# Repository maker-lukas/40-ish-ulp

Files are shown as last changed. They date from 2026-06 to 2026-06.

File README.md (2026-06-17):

# 40%ish ulp

> A split wireless 36 key keyboard powered by the Seeed XIAO Nrf52840 with cherry ULP switches.

<div>
  <a target="_blank" href="https://kicanvas.org/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">
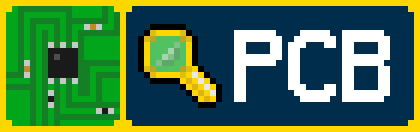
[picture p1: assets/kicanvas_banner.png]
View on KiCanvas
    
  </a>
</div>

<div>
  <a target="_blank" href="https://autode.sk/3Qic5Ux">
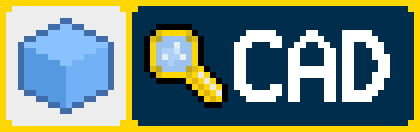
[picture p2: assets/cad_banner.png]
View CAD
    
  </a>
</div>

<div align="center">
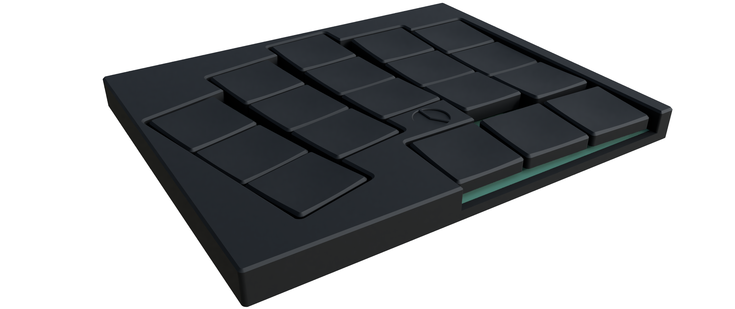
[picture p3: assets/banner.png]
  
</div>

---

**40%ish** ulp is a split, ultra low profile keyboard with a 36 key layout, which is great when you are traveling or like a clean and slim build on your desk. It's only 8.25mm thick, with a huge battery so you won't have to charge it every day. It even has a status LED to tell you when the battery is low. Being wireless, it can connect to any device. Using ZMK firmware, you can customize your layout on the fly inside your browser, and its really power efficient!

---

## Features

- 36 key split layout
- Wireless BLE with ZMK
- Cherry ULP switches
- Reversible PCB design

---

## BOM
 
| Part | Qty | Specification | Price | Link |
|---|-----|---|---|---|
| MCU | 2 | Seeed XIAO nRF52840 | $26.18 | [mauser.pt](https://mauser.pt/095-1482/seeed-102010448-microcontrolador-seeed-studio-xiao-nrf52840-c-bluetooth-5-0-ble-nfc-e-carregamento-de-bateria) |
| Switches (pack of 10) | 4 | Cherry ULP | $41.63 | [keeb.supply](https://keeb.supply/products/cherry-mx-ulp?variant=a840d9fa-f4e0-4218-be04-4d0f5e8f7554) |
| PCBs | 5 | Reversible, MOQ 5 | $11.06 | [jlcpcb.com](https://jlcpcb.com) |
| Batteries | 2 | 307095, 5000mAh battery | $16.23 | [aliexpress.com](https://pt.aliexpress.com/item/1005009973979747.html) |
| Diodes | 36 | SOD-123 | $1.57 | [aliexpress.com](https://pt.aliexpress.com/item/1005012163356976.html) |
| Power Switch | 2 | MK-12C02 | $0.87 | [aliexpress.com](https://pt.aliexpress.com/item/1005011530988236.html) |
| Reset Switch | 2 | EVQ-PUL02K | $1.87 | [aliexpress.com](https://pt.aliexpress.com/item/1005010726427079.html) |
| LEDs | 2 | WS2812B | $1.14 | [aliexpress.com](https://pt.aliexpress.com/item/1005008739048100.html) |
| Case | 2 | | $6.42 | [jlc3dp.com](https://jlc3dp.com) |
| Keycaps | 36 | Resin Printed | $37.46 | [jlc3dp.com](https://jlc3dp.com) |
| Magnets | 8 | 5x2mm round magnets | $2.88 | [aliexpress.com](https://pt.aliexpress.com/item/1005009605352565.html) |
| **Total** | | | **$147.31** | |

---

## Soldering notes

Because the PCB is reversible, some of the pins need to be reversed by bridging solder jumpers. Solder all 5 points shown in the images below for each side.

| Left | Right |
|:---:|:---:|
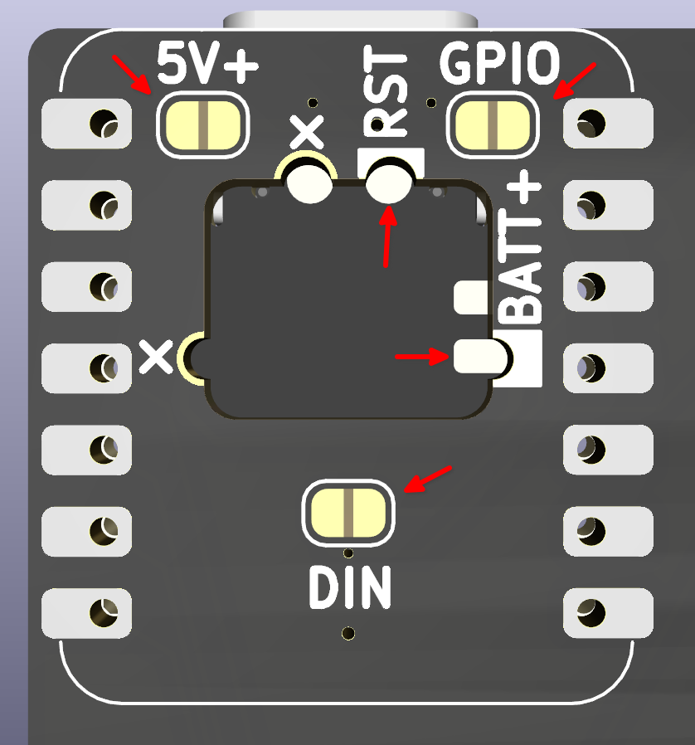
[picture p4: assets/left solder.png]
solder_left
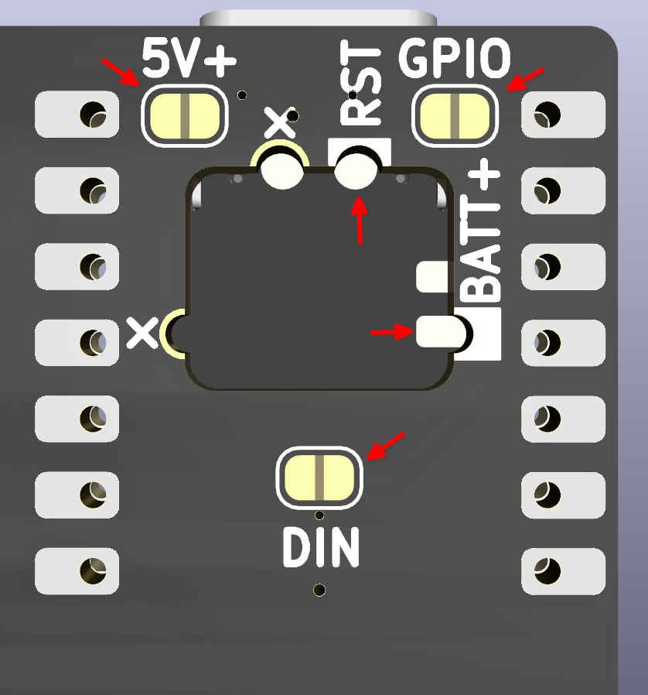
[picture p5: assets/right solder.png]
solder_right
|  |  |

---

## Pictures

| |
|:---:|
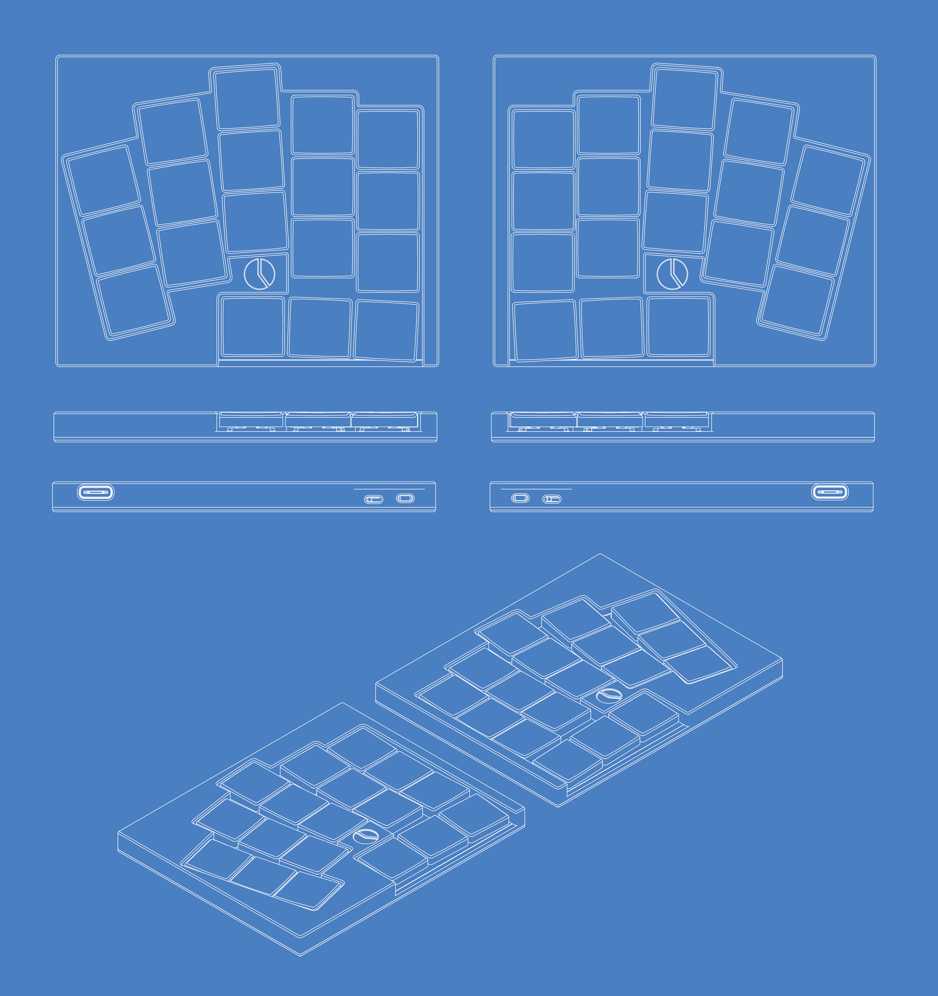
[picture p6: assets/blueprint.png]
blueprint
| **Blueprint**<br><br> |
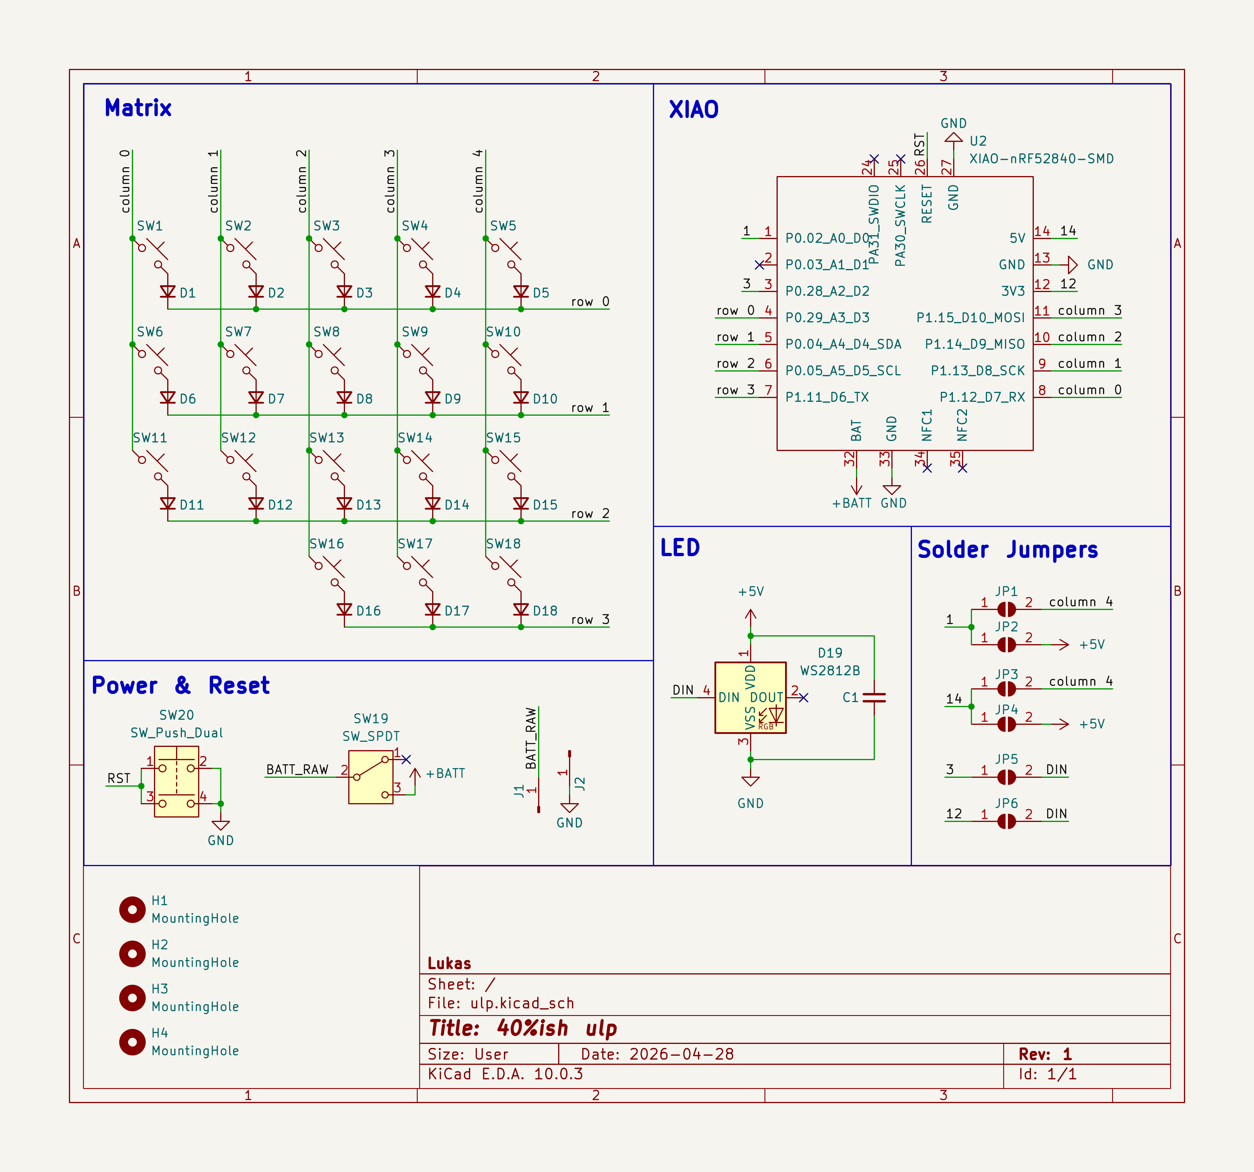
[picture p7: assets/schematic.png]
schematic
| **Schematic**<br><br> |
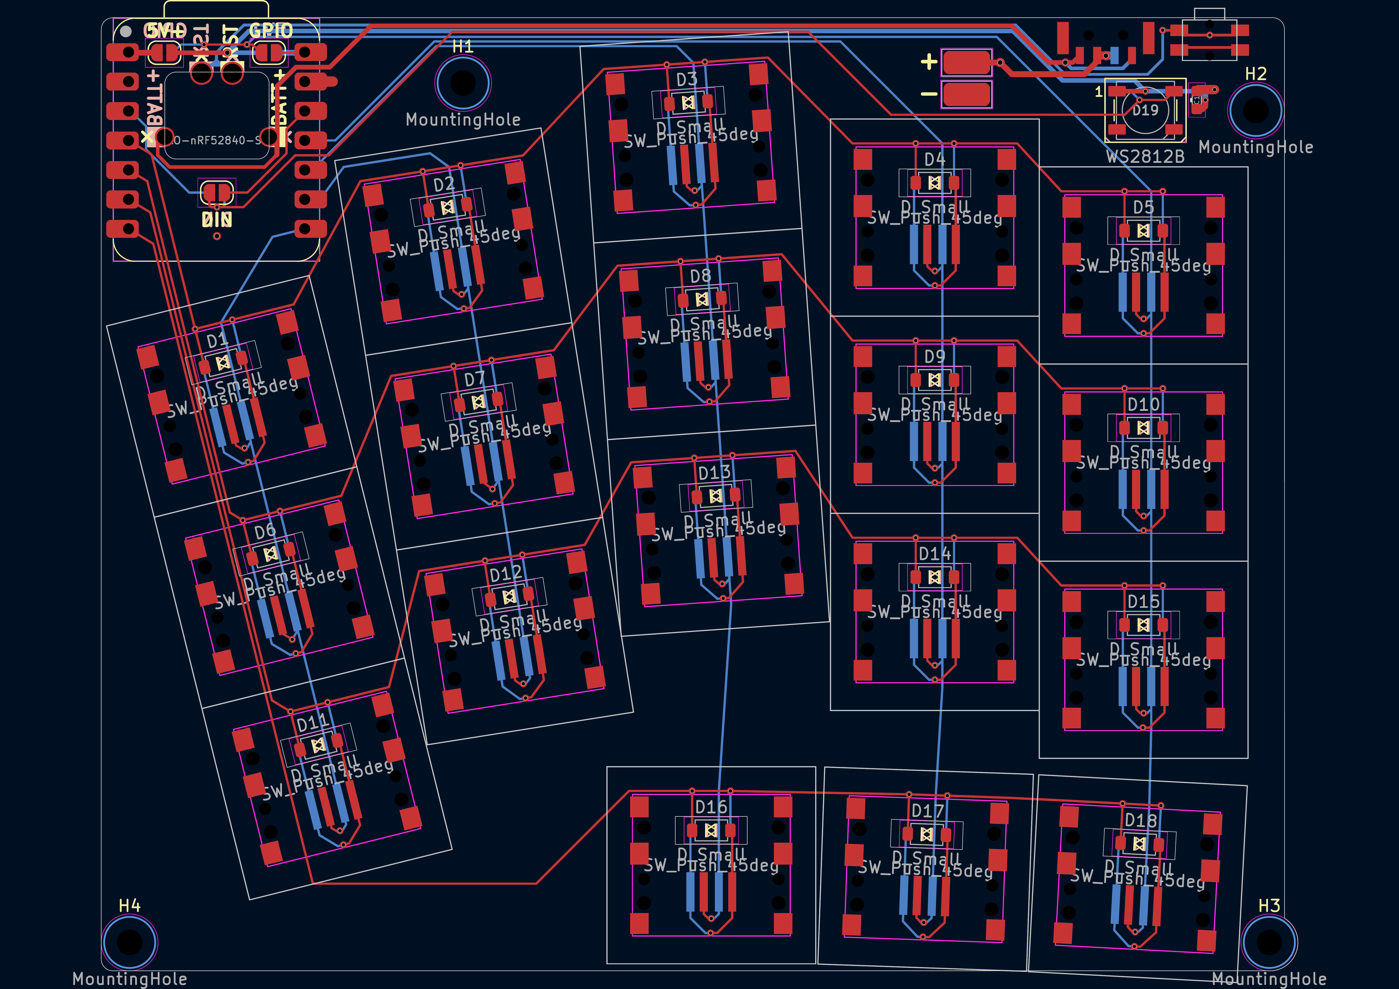
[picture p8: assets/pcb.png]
pcb
| **PCB**<br><br> |
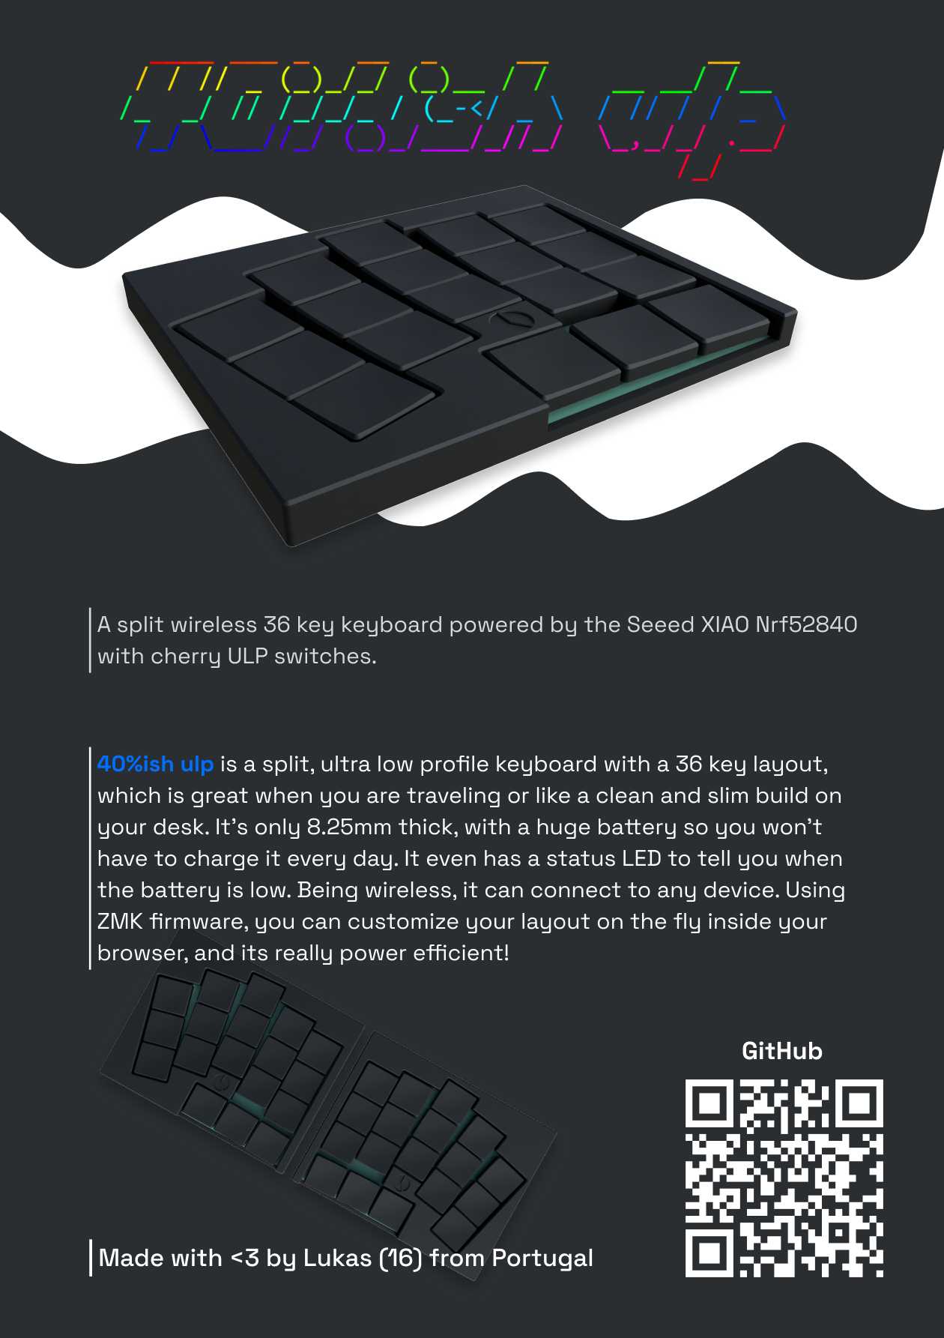
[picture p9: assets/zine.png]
zine
| **Zine**<br><br><br>[Full PDF](assets/zine.pdf) |

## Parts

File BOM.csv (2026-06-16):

Part | Qty | Specification | Price | Link
MCU | 2 | Seeed XIAO nRF52840 | $26.18 | https://mauser.pt/095-1482/seeed-102010448-microcontrolador-seeed-studio-xiao-nrf52840-c-bluetooth-5-0-ble-nfc-e-carregamento-de-bateria
Switches (pack of 10) | 4 | Cherry ULP | $41.63 | https://keeb.supply/products/cherry-mx-ulp?variant=a840d9fa-f4e0-4218-be04-4d0f5e8f7554
PCBs | 5 | Reversible, MOQ 5 | $11.06 | https://jlcpcb.com
Batteries | 2 | 307095, 5000mAh battery | $16.23 | https://pt.aliexpress.com/item/1005009973979747.html
Diodes | 36 | SOD-123 | $1.57 | https://pt.aliexpress.com/item/1005012163356976.html
Power Switch | 2 | MK-12C02 | $0.87 | https://pt.aliexpress.com/item/1005011530988236.html
Reset Switch | 2 | EVQ-PUL02K | $1.87 | https://pt.aliexpress.com/item/1005010726427079.html
LEDs | 2 | WS2812B | $1.14 | https://pt.aliexpress.com/item/1005008739048100.html
Case | 2 |  | $6.42 | https://jlc3dp.com
Keycaps | 36 | Resin Printed | $37.46 | https://jlc3dp.com
magnets | 8 | 5x2mm round magnets | $2.88 | https://pt.aliexpress.com/item/1005009605352565.html
Total |  |  | 147.31

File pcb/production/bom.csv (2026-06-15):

Designator | Footprint | Quantity | Value | LCSC Part #
C1 | 0603 | 1 | C_Small
D1, D10, D11, D12, D13, D14, D15, D16, D17, D18, D2, D3, D4, D5, D6, D7, D8, D9 | D_SOD-123_Reversible | 18 | D_Small
D19 | LED_WS2812B_PLCC4_5.0x5.0mm_P3.2mm_Reversible | 1 | WS2812B
J1, J2 | TestPoint_Pad_2.0x4.0mm_Reversible | 2 | Conn_01x01_Pin
SW1, SW10, SW11, SW12, SW13, SW14, SW15, SW16, SW17, SW18, SW2, SW3, SW4, SW5, SW6, SW7, SW8, SW9 | Cherry_ULP_SMD_Double_Sided | 18 | SW_Push_45deg
SW19 | SW_SPDT_MSK-12C02_Reversible | 1 | SW_SPDT | C2911519
SW20 | SW_Push_SPST_EVQ-PU_Reversible | 1 | SW_Push_Dual | C79175
U2 | MODULE_Seeed_XIAO_nRF52840_THT_Reversible | 1 | XIAO-nRF52840-SMD

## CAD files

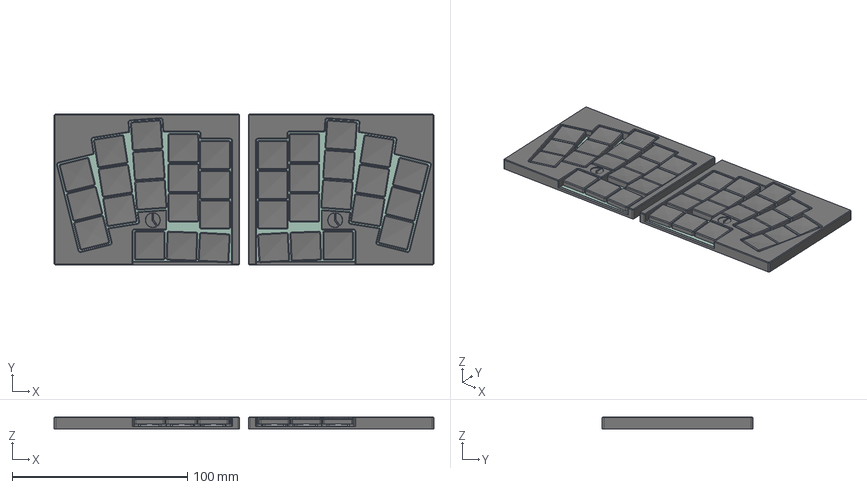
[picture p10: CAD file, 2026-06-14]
case/40%ish ulp.step
216.7 x 86.1 x 7.00 mm
D_SOD-123_1 x 18
LED_WS2812B_PLCC4_50x50mm_P32mm
C_0603_1608Metric_1
MSK12C02 v3
BOSS-EXTRUDE14_8_
BOSS-EXTRUDE7_4_
BOSS-EXTRUDE7_3_
BOSS-EXTRUDE14_4_
BOSS-EXTRUDE14_2_
BOSS-EXTRUDE14_11_
BOSS-EXTRUDE7_7_
BOSS-EXTRUDE14_9_
BOSS-EXTRUDE14_3_
BOSS-EXTRUDE14_7_
MIRROR2
BOSS-EXTRUDE14_5_
BOSS-EXTRUDE14_12_
BOSS-EXTRUDE7_8_
BOSS-EXTRUDE7_1_
BOSS-EXTRUDE14_10_
BOSS-EXTRUDE7_9_
BOSS-EXTRUDE14_6_
BOSS-EXTRUDE14_1_
BOSS-EXTRUDE7_6_
BOSS-EXTRUDE7_2_
CUT-EXTRUDE5
BOSS-EXTRUDE7_5_
Shield
Pins
CAP x 2
ANT1
Silkscreen
CAP 3
LED
USR
EVQPUC02K
ulp_PCB
D_SOD-123_20 x 18
LED_WS2812B_PLCC4_50x50mm_P32mm_1
C_0603_1608Metric_3
MSK12C02 v3_1
BOSS-EXTRUDE14_8__1
BOSS-EXTRUDE7_4__1
BOSS-EXTRUDE7_3__1
BOSS-EXTRUDE14_4__1
BOSS-EXTRUDE14_2__1
BOSS-EXTRUDE14_11__1
BOSS-EXTRUDE7_7__1
BOSS-EXTRUDE14_9__1
BOSS-EXTRUDE14_3__1
BOSS-EXTRUDE14_7__1
MIRROR2_1
BOSS-EXTRUDE14_5__1
BOSS-EXTRUDE14_12__1
BOSS-EXTRUDE7_8__1
BOSS-EXTRUDE7_1__1
BOSS-EXTRUDE14_10__1
BOSS-EXTRUDE7_9__1
BOSS-EXTRUDE14_6__1
BOSS-EXTRUDE14_1__1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

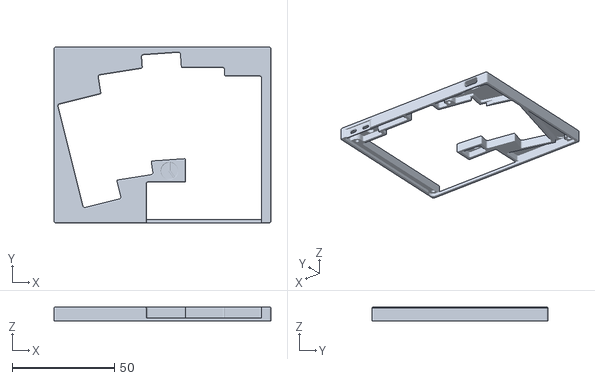
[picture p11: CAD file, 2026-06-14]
case/Left/Case Left.stl
105.9 x 86.1 x 7.00

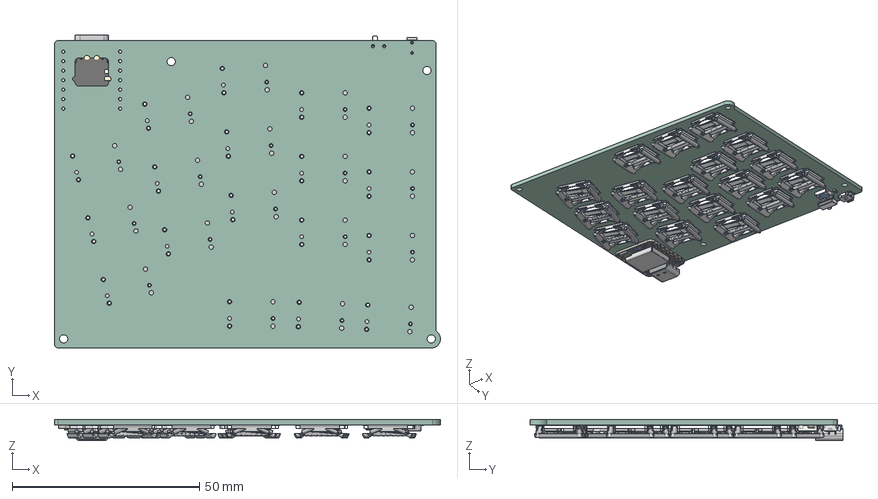
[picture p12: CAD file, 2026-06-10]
pcb/exports/right_ulp.step
103.2 x 83.7 x 5.73 mm
D_SOD-123 x 18
LED_WS2812B_PLCC4_50x50mm_P32mm
C_0603_1608Metric
MSK12C02 v3
BOSS-EXTRUDE14_8_
BOSS-EXTRUDE7_4_
BOSS-EXTRUDE7_3_
BOSS-EXTRUDE14_4_
BOSS-EXTRUDE14_2_
BOSS-EXTRUDE14_11_
BOSS-EXTRUDE7_7_
BOSS-EXTRUDE14_9_
BOSS-EXTRUDE14_3_
BOSS-EXTRUDE14_7_
MIRROR2
BOSS-EXTRUDE14_5_
BOSS-EXTRUDE14_12_
BOSS-EXTRUDE7_8_
BOSS-EXTRUDE7_1_
BOSS-EXTRUDE14_10_
BOSS-EXTRUDE7_9_
BOSS-EXTRUDE14_6_
BOSS-EXTRUDE14_1_
BOSS-EXTRUDE7_6_
BOSS-EXTRUDE7_2_
CUT-EXTRUDE5
BOSS-EXTRUDE7_5_
Shield
Pins
CAP x 2
ANT1
Silkscreen
CAP 3
LED
USR
2 v1
EVQPUC02K
ulp_PCB

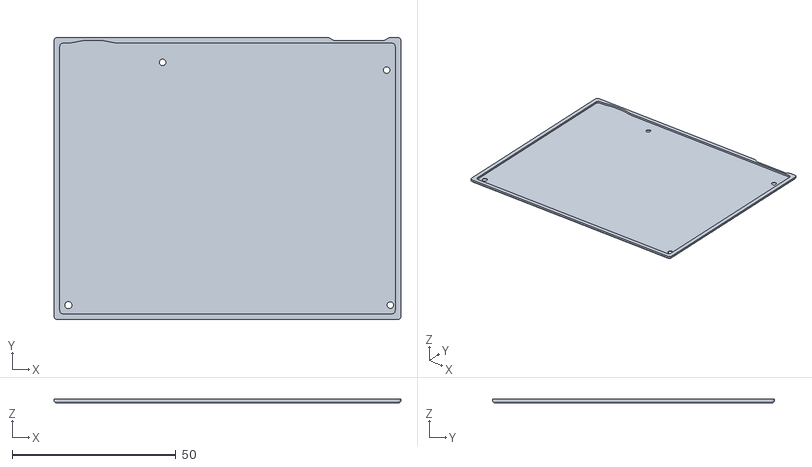
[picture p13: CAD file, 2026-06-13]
case/Left/Bottom Left.stl
105.9 x 86.1 x 1.25

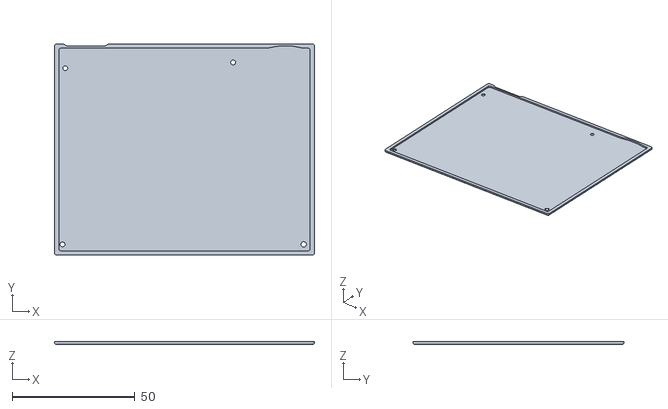
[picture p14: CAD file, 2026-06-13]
case/Right/Bottom Right.stl
105.9 x 86.1 x 1.25

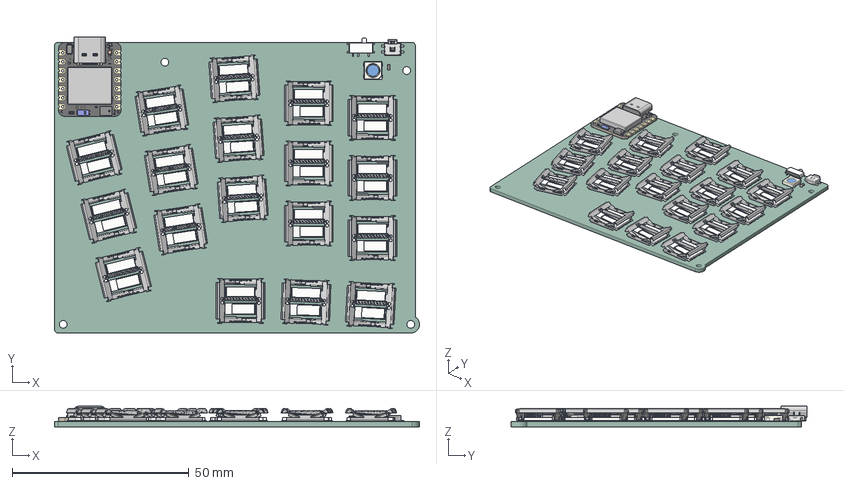
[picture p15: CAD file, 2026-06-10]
pcb/exports/left_ulp.step
103.2 x 83.7 x 5.81 mm
D_SOD-123 x 18
LED_WS2812B_PLCC4_50x50mm_P32mm
C_0603_1608Metric
MSK12C02 v3
BOSS-EXTRUDE14_8_
BOSS-EXTRUDE7_4_
BOSS-EXTRUDE7_3_
BOSS-EXTRUDE14_4_
BOSS-EXTRUDE14_2_
BOSS-EXTRUDE14_11_
BOSS-EXTRUDE7_7_
BOSS-EXTRUDE14_9_
BOSS-EXTRUDE14_3_
BOSS-EXTRUDE14_7_
MIRROR2
BOSS-EXTRUDE14_5_
BOSS-EXTRUDE14_12_
BOSS-EXTRUDE7_8_
BOSS-EXTRUDE7_1_
BOSS-EXTRUDE14_10_
BOSS-EXTRUDE7_9_
BOSS-EXTRUDE14_6_
BOSS-EXTRUDE14_1_
BOSS-EXTRUDE7_6_
BOSS-EXTRUDE7_2_
CUT-EXTRUDE5
BOSS-EXTRUDE7_5_
Shield
Pins
CAP x 2
ANT1
Silkscreen
CAP 3
LED
USR
2 v1
EVQPUC02K
ulp_PCB

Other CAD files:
case/Right/Case Right.stl
case/40%ish ulp.f3z

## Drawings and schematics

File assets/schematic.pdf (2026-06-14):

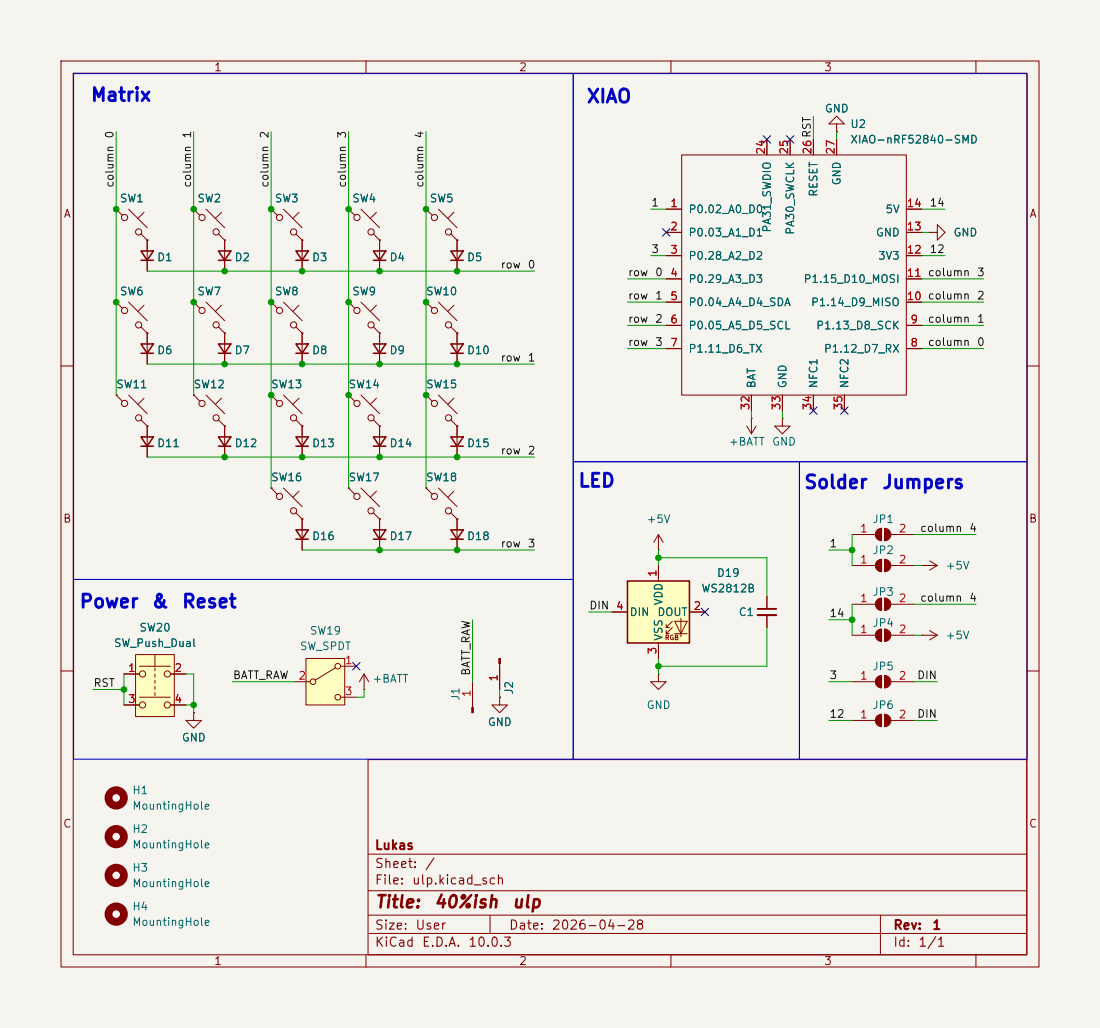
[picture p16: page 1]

GND

LED | | JP3 +BATT GND JP5

Lukas

Size: User | Rev: 1
KiCad E.D.A. 10.0.3 | Id: 1/1

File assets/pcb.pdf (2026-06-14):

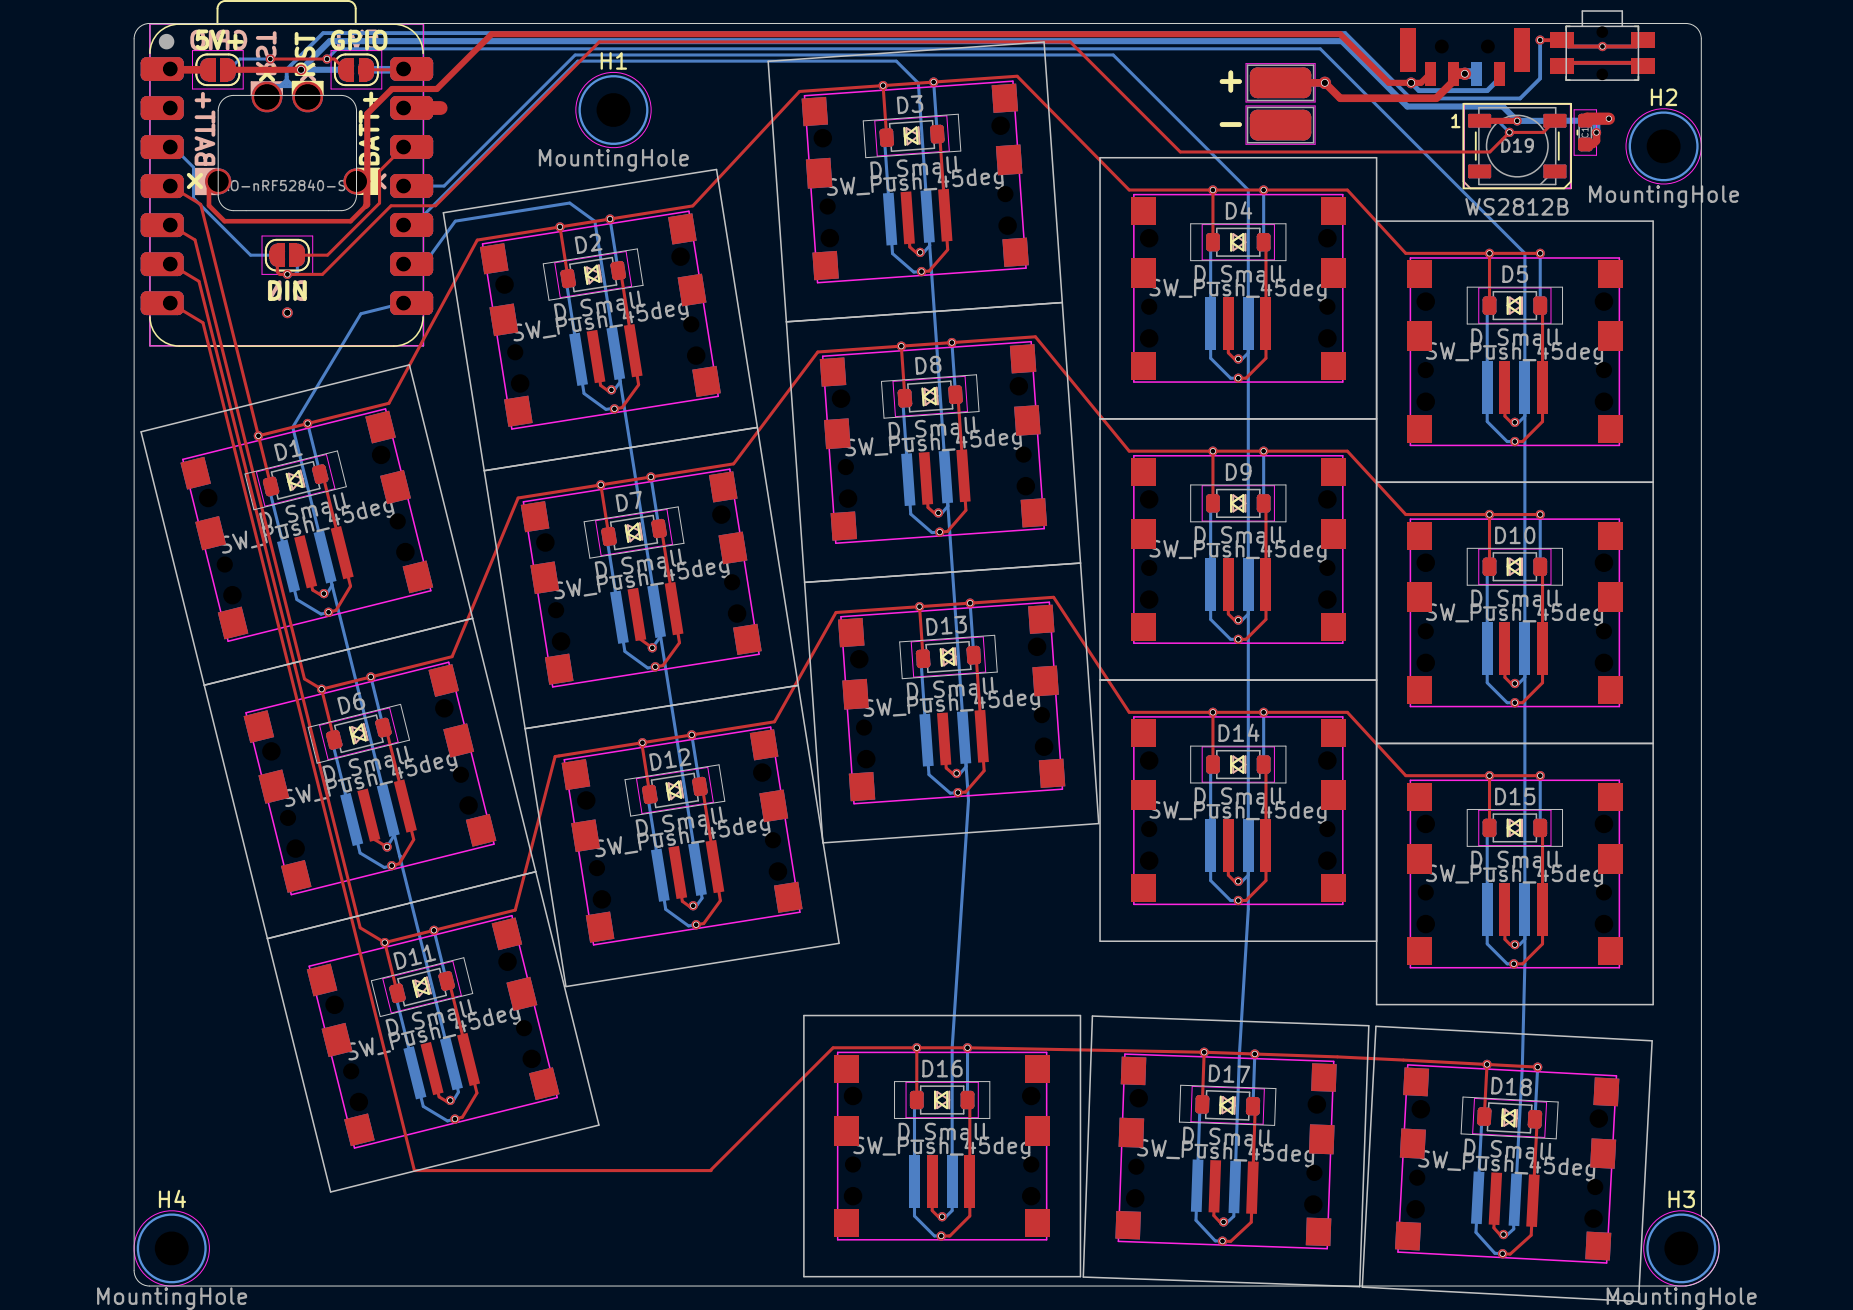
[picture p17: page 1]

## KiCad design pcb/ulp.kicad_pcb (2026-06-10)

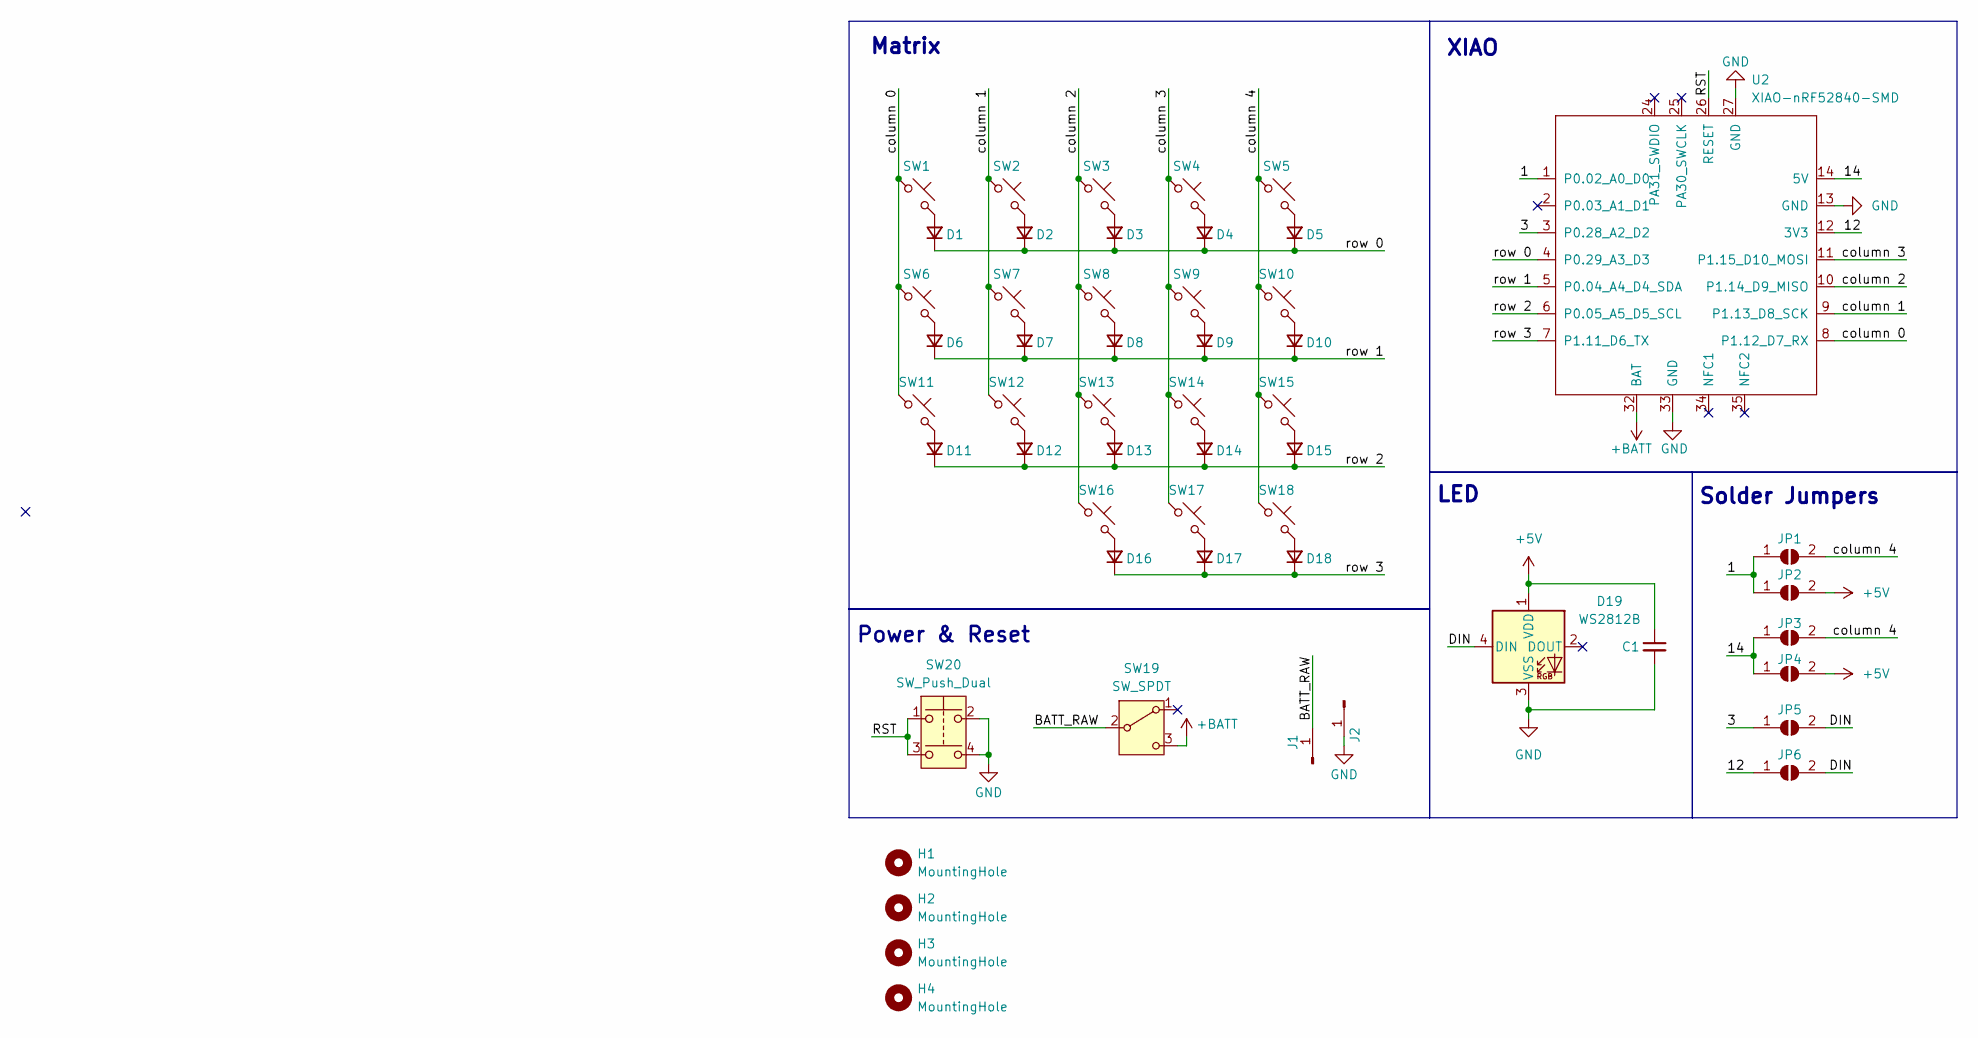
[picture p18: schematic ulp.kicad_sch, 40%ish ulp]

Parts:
C1: C_Small; C_0603_1608Metric_Reversible
D1, D2, D3, D4, D5, D6, D7, D8, D9, D10, D11, D12, D13, D14, D15, D16, D17, D18: D_Small; D_SOD-123_Reversible
D19: WS2812B; LED_WS2812B_PLCC4_5.0x5.0mm_P3.2mm_Reversible
H1, H2, H3, H4: MountingHole; MountingHole_2.2mm_M2
J1, J2: Conn_01x01_Pin; TestPoint_Pad_2.0x4.0mm_Reversible
JP1, JP2, JP3, JP4, JP5, JP6: SolderJumper_2_Open; SolderJumper-2_P1.3mm_Open_RoundedPad1.0x1.5mm
SW1, SW2, SW3, SW4, SW5, SW6, SW7, SW8, SW9, SW10, SW11, SW12, SW13, SW14, SW15, SW16, SW17, SW18: SW_Push_45deg; Cherry_ULP_SMD_Double_Sided
SW19: SW_SPDT; SW_SPDT_MSK-12C02_Reversible
SW20: SW_Push_Dual; SW_Push_SPST_EVQ-PU_Reversible
U2: XIAO-nRF52840-SMD; MODULE_Seeed_XIAO_nRF52840_THT_Reversible

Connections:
+5V: C1.1, D19.1 (VDD), JP2.2 (B), JP4.2 (B)
+BATT: SW19.3 (C), U2.32 (BAT)
/1: JP1.1 (A), JP2.1 (A), U2.1 (P0.02_A0_D0)
/3: JP5.1 (A), U2.3 (P0.28_A2_D2)
/12: JP6.1 (A), U2.12 (3V3)
/14: JP3.1 (A), JP4.1 (A), U2.14 (5V)
/BATT_RAW: J1.1 (Pin_1_1), SW19.2 (B)
/DIN: D19.4 (DIN), JP5.2 (B), JP6.2 (B)
/RST: SW20.1, SW20.3, U2.26 (RESET)
/column 0: SW1.1, SW6.1, SW11.1, U2.8 (P1.12_D7_RX)
/column 1: SW2.1, SW7.1, SW12.1, U2.9 (P1.13_D8_SCK)
/column 2: SW3.1, SW8.1, SW13.1, SW16.1, U2.10 (P1.14_D9_MISO)
/column 3: SW4.1, SW9.1, SW14.1, SW17.1, U2.11 (P1.15_D10_MOSI)
/column 4: JP1.2 (B), JP3.2 (B), SW5.1, SW10.1, SW15.1, SW18.1
/row 0: D1.1 (K), D2.1 (K), D3.1 (K), D4.1 (K), D5.1 (K), U2.4 (P0.29_A3_D3)
/row 1: D6.1 (K), D7.1 (K), D8.1 (K), D9.1 (K), D10.1 (K), U2.5 (P0.04_A4_D4_SDA)
/row 2: D11.1 (K), D12.1 (K), D13.1 (K), D14.1 (K), D15.1 (K), U2.6 (P0.05_A5_D5_SCL)
/row 3: D16.1 (K), D17.1 (K), D18.1 (K), U2.7 (P1.11_D6_TX)
GND: C1.2, D19.3 (VSS), J2.1 (Pin_1_1), SW20.2, SW20.4, U2.13 (GND), U2.27 (GND), U2.33 (GND)
unnamed: D1.2 (A), SW1.2
unnamed: D2.2 (A), SW2.2
unnamed: D3.2 (A), SW3.2
unnamed: D4.2 (A), SW4.2
unnamed: D5.2 (A), SW5.2
unnamed: D6.2 (A), SW6.2
unnamed: D7.2 (A), SW7.2
unnamed: D8.2 (A), SW8.2
unnamed: D9.2 (A), SW9.2
unnamed: D10.2 (A), SW10.2
unnamed: D11.2 (A), SW11.2
unnamed: D12.2 (A), SW12.2
unnamed: D13.2 (A), SW13.2
unnamed: D14.2 (A), SW14.2
unnamed: D15.2 (A), SW15.2
unnamed: D16.2 (A), SW16.2
unnamed: D17.2 (A), SW17.2
unnamed: D18.2 (A), SW18.2

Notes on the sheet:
Matrix
LED
XIAO
Power & Reset
Solder Jumpers

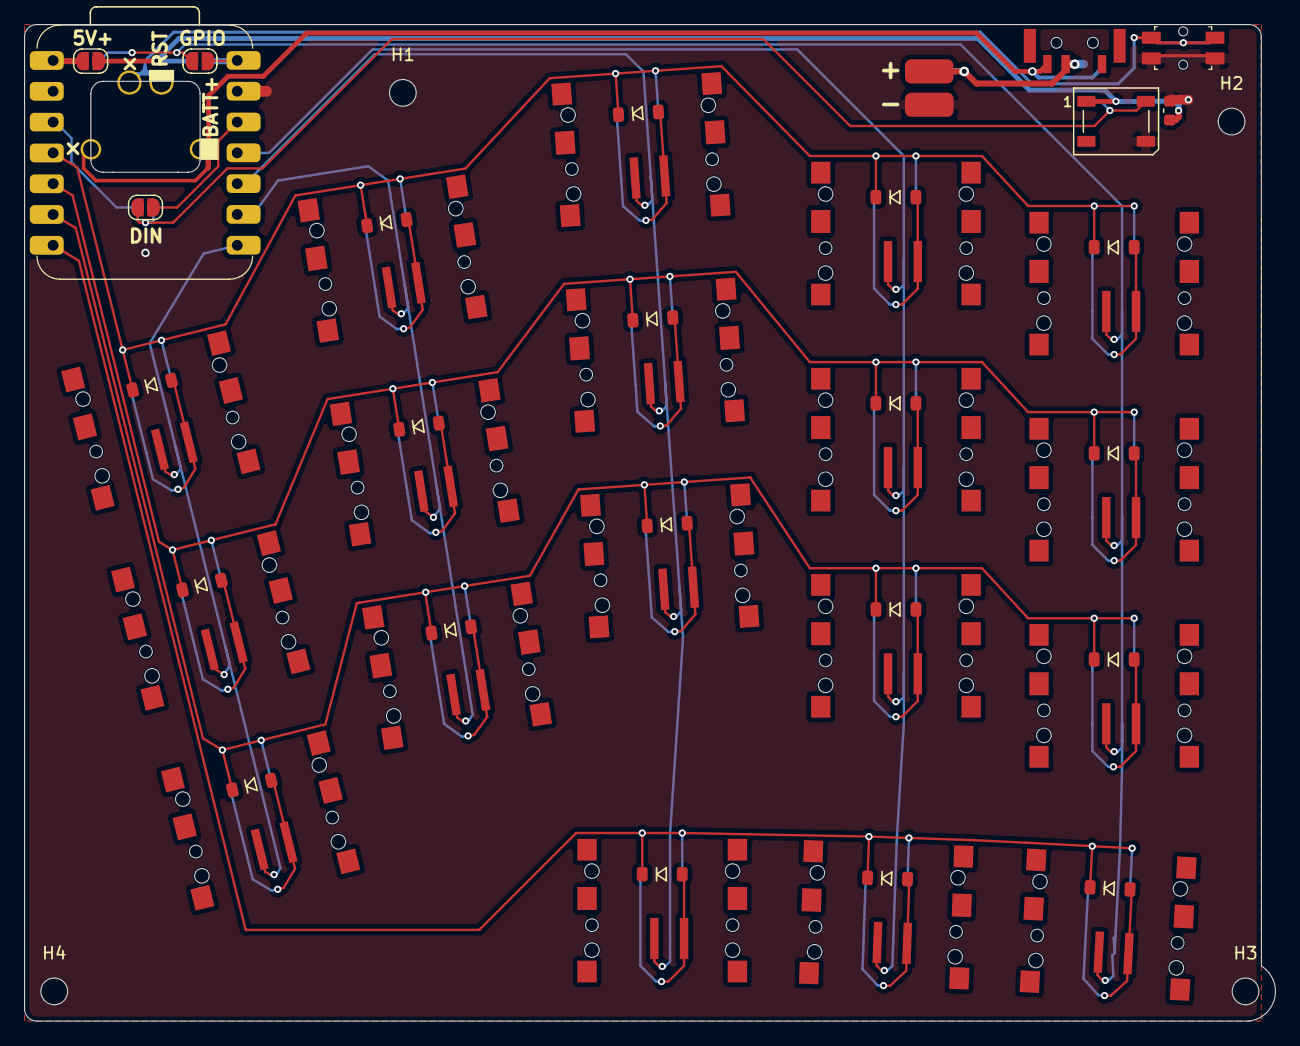
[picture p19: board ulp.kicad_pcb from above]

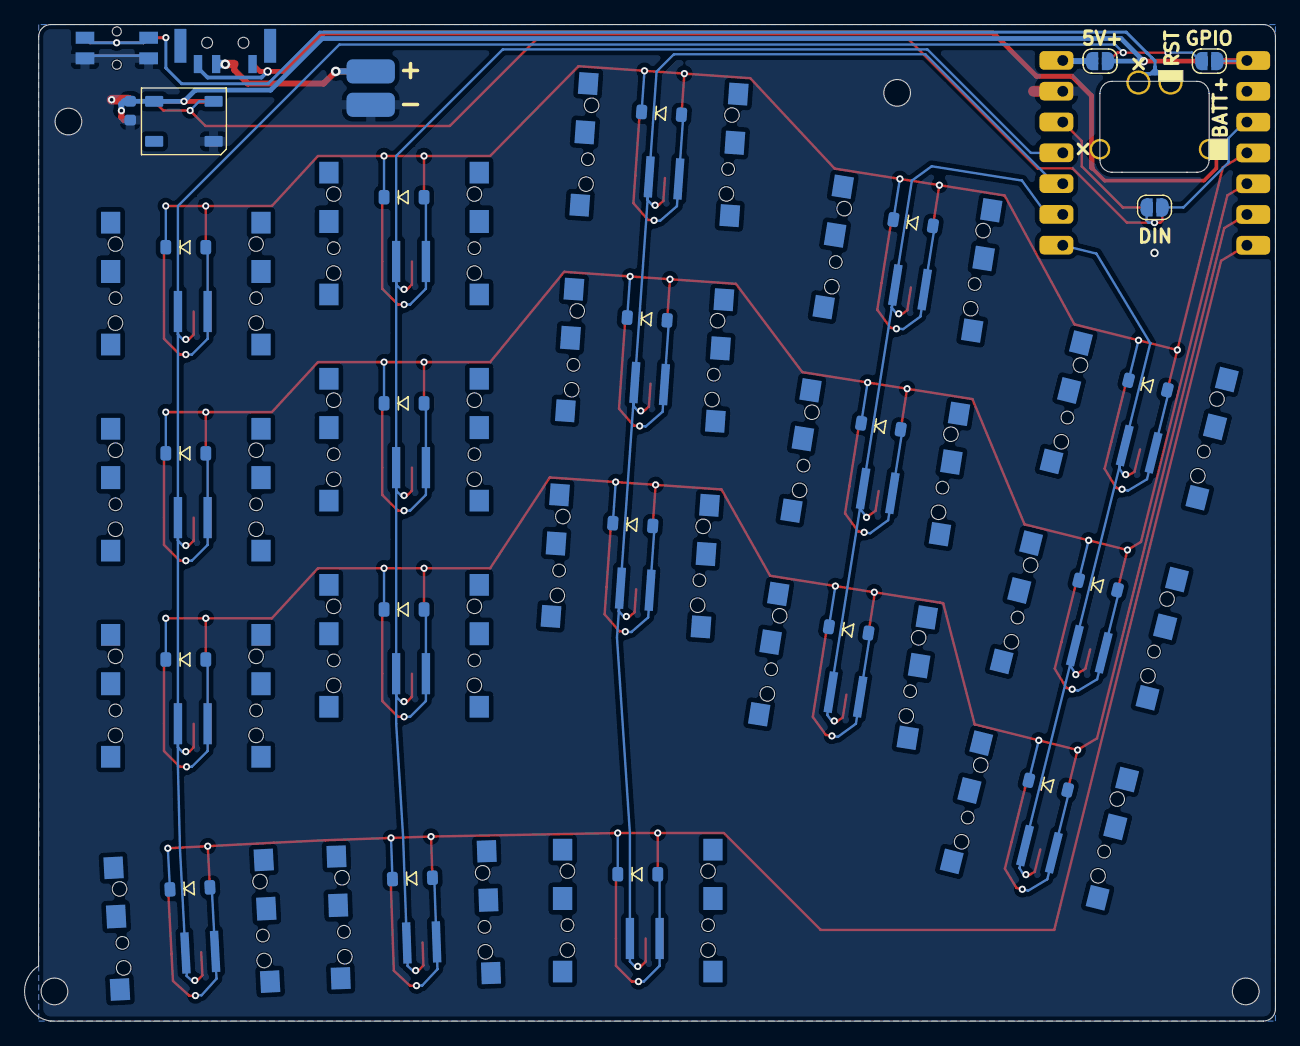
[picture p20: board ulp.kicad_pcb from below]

Board: 2 copper layers, 103.2 x 82.2 mm, 53 parts (3 on the bottom side), 37 nets.

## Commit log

2026-05-29 add pcb files
    [ulp.kicad_pcb, ulp.kicad_sch]
2026-05-29 Stop tracking ulp-backups
    Amp-Thread-ID: https://ampcode.com/threads/T-019e7445-9c97-7198-8a44-fdf52582fa4e
2026-05-29 small changes
    [ulp.kicad_pcb]
2026-05-29 remove layer
    [ulp.kicad_pcb]
2026-05-29 Stop tracking ignored files
    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
    [ulp.kicad_pcb]
2026-05-31 update pcb
    [ulp.kicad_pcb, ulp.kicad_sch]
2026-05-31 add .step files of each side
    [left_ulp.step, right_ulp.step, ulp.kicad_pcb]
2026-05-31 update .step files
    [left_ulp.step, right_ulp.step, ulp.kicad_pcb]
2026-06-05 change board outline
    [left_ulp.step, ulp.kicad_pcb]
2026-06-05 test commit
    [ulp.kicad_pcb]
2026-06-06 add new pcb stuff
    [left_ulp.step, ulp.kicad_pcb]
2026-06-09 Update README with features and BOM
    Added detailed features and BOM for the 40%ush ULP keyboard.
2026-06-09 Update prices and links for power and reset switches
2026-06-09 Update keycaps entry with material and price
2026-06-09 Add price and link for WS2812B LEDs
2026-06-10 add mounting holes and new models
    [left_ulp.step, right_ulp.step, ulp.kicad_pcb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]
2026-06-10 restructure repo to clean up
    [left_ulp.step, right_ulp.step, ulp.kicad_pcb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]
2026-06-13 add all case and firmware files
    [40%ish ulp.f3z, 40%ish ulp.step, Bottom Left.stl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]
2026-06-14 add new 3D files
    [40%ish ulp.f3z, 40%ish ulp.step, Case Left.stl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]
2026-06-14 add schematic and PCB images to README
2026-06-15 add production files + update BOM
2026-06-15 adding BOM
    [BOM.csv, bom.csv, designators.csv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]
2026-06-15 Ignore KiCad library tables and fabrication toolkit options
    Amp-Thread-ID: https://ampcode.com/threads/T-019ecb23-611f-761b-a8e9-f24c43f40df0
2026-06-15 add magnets to BOM
    [BOM.csv]
2026-06-16 add cad banner
2026-06-16 add battery pricing and link
    [BOM.csv]
2026-06-17 add little documentaito on how to solder
